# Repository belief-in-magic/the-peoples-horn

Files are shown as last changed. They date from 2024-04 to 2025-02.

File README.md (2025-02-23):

# HERE LIES

This project is no longer actively developed. 

I've decided to open-source all the components (pcb, case design, and firmware) for anyone interested. There are a couple of bits that may be useful
for anyone trying to do something similar.

Please see [EPILOGUE.md](/EPILOGUE.md) for more details

# The People's Horn

One word: WHIMSY.

The People's Horn is a portable soundboard that can be operated with a single hand. 
The chorded input interface allows for 15 (2^4-1) sounds to be played. 

## DEMO

https://github.com/user-attachments/assets/fd60f254-f890-4aff-ada0-f0f0ac13cf6f

## Basic usage

- On the main board (the one with the RP2040, uSD slot, and USB-C connector), there should be a power jumper (POWER_EN)
This needs to be shorted for the board to power on.
- Slot in the microSD card with sound files stored inside. The format and naming of said sound files are explained below.
- Insert the speaker leads into the green terminal block. Note the polarity of the leads. ([PCB/v0.2 only] There aren't any signifiers for the polarity of the leads on the PCB. The one 
soldered to the square pad on the PCB is the positive one.)
- Connect the IO board with the main board using the JST connector.
- Compile and upload the firmware. This is described in the firmware directory README.

## Loading files

Sound files are stored in an external uSD card. Current limitations in the hardware require that the sound files to be in a certain format. Notably they need to be in `.wav` format, with a mono 44.1kHz sampling rate.

Here is a nice ffmpeg command to convert an example file `0001.mp3` into a compliant `wav` file:

```
ffmpeg -i 0001.mp3 -f wav  -flags +bitexact -map_metadata -1 -ar 44100 -ac 1 -af "highpass=f=120,highpass=f=100,lowpass=f=19000,lowpass=f=20000" 0001.wav
```

The names of the final sound files also need to follow a specific format: `[0|1][0|1][0|1][0|1].wav` (e.g. `1001.wav`, `0111.wav`). The number in the filename represents the buttons to
press in order to play it. The lowest order bit represents the button closest to the rotary encoder. The highest order bit is the one furthest away.

## Current Bugs:

- [PCB/v0.3]: Current main board seems to not work directly on USB power. If the battery is not connected but the USB port is,
the board should power on. This is not the case with v0.2. This might be caused by the main inductor backdriving (?). This is hopefully fixed with the new diode placement.
  - Update: this is still the case with v0.3 :( 

## TODO + Possible Improvements:

- [PCB]: Power usage testing. Test low power mode for the rp2040. 
  - How long does it take to fully charge? 
  - How long does a charge last idle?
  - Does using the rp2040 lower power mode make sense?
- [PCB]: Separate 3.3V and 5V converters from battery. Currently we use a 3.3V LDO regulator on the boosted 5V source, this isn't the most
efficient. If we have a separate 3.3V SMPS from battery, we could also disable the 5V converter during lower power situations, allowing for
even more energy savings.

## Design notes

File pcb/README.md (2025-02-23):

# PCB

KiCAD (6.0) schematic and PCB files.

There are technically two KiCAD projects here. One for the "main" board and one for the
IO board. 

Supporting multiple PCBs in one KiCAD project is kinda janky right now. So it was decided 
to use different projects. This allows us to iterate separately on these boards. It also seems to be
easier for fab houses to process and manufacture, without dramatically increasing the price. 

We might have to eventually reconsider using two separate projects for scale and cost purposes, but for dev work this seems to work fine.

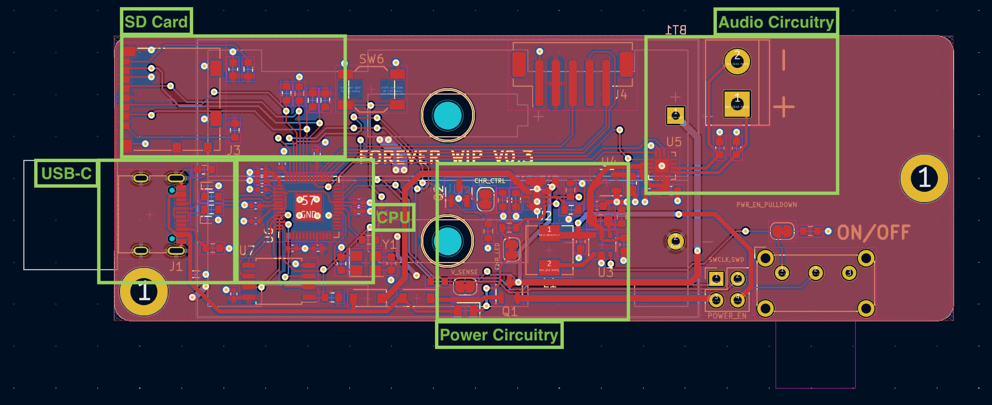
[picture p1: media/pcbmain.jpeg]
main board pcb


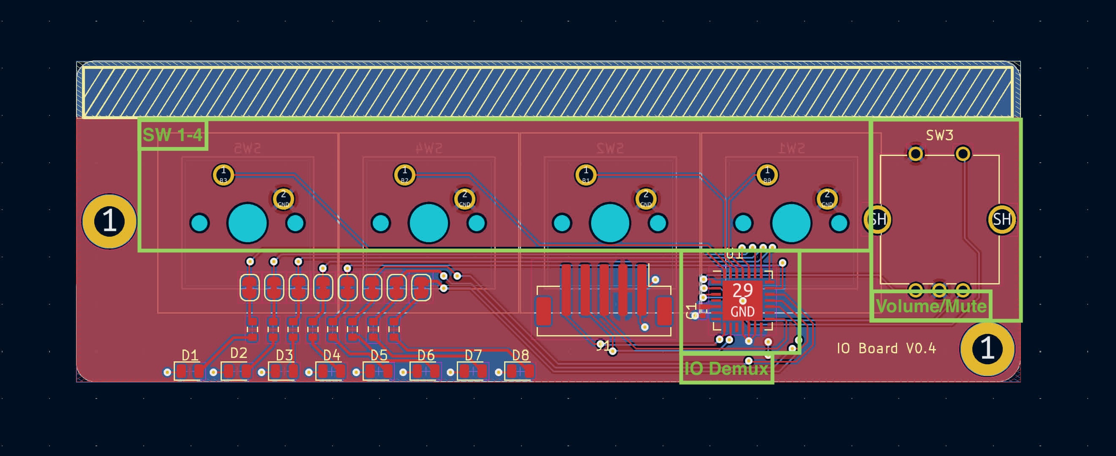
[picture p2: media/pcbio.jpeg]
io board pcb


## Version:

[VERSION 0.3] 
SHA: e7d5517

## Preparing boards for manufacturing

TODO

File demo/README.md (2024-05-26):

# Demo script to test with keyboard

Python script to test basic UX for chorded sounds. Just a demo. Not used in any
way in the main project.

Needs pygame:
```
pip3 install pygame
```

Run:
```
python3 keyboard.py
```

A small blank screen will appear once you run the script. 
Click on the screen and play sounds with the 1,2,3,4 keyboard keys.
Cancel all currently playing sounds with spacebar.

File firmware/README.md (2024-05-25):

# Firmware source code

Arduino sketch for main board. We use the arduino-cli and an open-source rp2040 core.
Arduino was chose here for its ease of use and the breadth of its peripheral libraries.

## Install:
Run this within the containing directory:
```
# Install arduino-cli in local directory
curl -fsSL https://raw.githubusercontent.com/arduino/arduino-cli/master/install.sh | BINDIR=$PWD sh

# Install arduino rp2040 core 
./arduino-cli config add board_manager.additional_urls  https://github.com/earlephilhower/arduino-pico/releases/download/global/package_rp2040_index.json
./arduino-cli core update-index
./arduino-cli core install rp2040:rp2040
```

### Compiling:

```
./arduino-cli compile --fqbn rp2040:rp2040:rpipico main
```

### Uploading:

```
./arduino-cli upload -p /dev/ttyACM0 --fqbn rp2040:rp2040:rpipico main
```

## Serial debugging:

You can start a serial connection with minicom:

```
minicom -D /dev/ttyACM0 -b 115200
```

## Language Server

TODO: I can't get this fucking thing to work

```
./arduino-language-server \
 -clangd /usr/bin/clangd \
 -cli ../arduino-cli \
 -cli-config $HOME/.arduino15/arduino-cli.yaml \
 -fqbn rp2040:rp2040:rpipico main
```

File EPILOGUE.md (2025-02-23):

# Epilogue

*This project is no longer actively developed!!!*

I've decided to open-source all the components (PCB, case design, and firmware) for anyone interested. There are a couple of bits that may be useful
for anyone trying to do something similar.

Firmware:
- How to read wav files from an sd interface and play multiple at once
- Control logic for a chorded input type-thing
- Using software fifo-queues for orchestrating the two RP2040 cores 

PCB:
- Reading from an SD card (using SPI) using an RP2040 chip 
- NiMh battery charging circuitry (honestly this is probably kinda buggy)
- Probably more...

## Writeup

I started this project back in November 2023 (roughly 1.5 years ago) and worked on it (on and off) for almost a year.
Development stopped when my personal priorities shifted and I started looking for a new job. The new job I landed
requires more of my energy and I don't see myself working on this project in the future. 

It wasn't for nothing though! I learnt a lot. I even took some prototypes out with me during hangouts with friends. This thing really is a tomfoolery device. 

I would say this project is probably around 90% complete; the core functionality is there, and what's left is mainly ironing out some hardware bugs
and polishing. (I say 90% done, but the last 10% is probably another 90% of work!) It's unfortunate that I'm not neatly tying everything up here, but I
feel like I've personally squeezed out everything I want from this project. 

This project was definitely a learning experience:
- Designing a custom PCB and shipping its various iterations for manufacturing was really fun. I've acquired a new appreciation for how fast
iteration cycles are for software. It was also really expensive! Canadian tariffs on PCBs really add up!
- Writing software for hardware that you've personally designed is also fun. I've never had to think about whether a feature should be represented in hardware or
software. I've also never really debugged issues where I was unsure if the problem came from the hardware or software! These were all very novel 
experiences for me.
- Designing the case presented me with some unfamiliar design challenges. The intent was to be able to use the horn with just one hand. I had to consider 
seemingly obvious design-y things: Can this be comfortably held? Is the mute button easily accesible? Is the case handle the occasional drop? 
I had to do this all while factoring in the physical constraints brought on by the PCBs. 

I had also originally intended to sell a couple of these. (I think the personal target I set for myself was 100?) Looking back, this was a pretty misguided
endeavor and I'm glad I didn't really continue there. The unit economics just didn't add up. I'd have to sell an individual unit for like $100, which is
way too much for a toy like this. There's also incorporating into a company, setting up manufacturing contracts, QA and insurance, marketing, setting up a website,
handling storage, handling returns, etc etc. Maybe for a different product in the future, but not this one.

## Technical stuff

All the components of this project (the case, PCB, software) went through at least one redesign, each. (A pattern I've noticed in nearly all my personal projects.)

### Firmware: 

The V1 firmware used shared memory and locks to communicate between the two RP2040 cores. One would look for user input chords, and the other would read from the sd card interface
and drive the speakers. Debugging this setup was a *complete* nightmare. This was at least partly due to my inexperience with lower level multiprocessing. The dance between
reading sd contents to memory buffers, getting "interrupted" by the IO core, and driving the audio chip became really clumsy, really fast. That was also exhasperbated by fact that multiple
sounds could be played at the same time (4 sounds to be exact, so 4 different sound buffers). The max number of sounds was mainly constrained
by how fast the RP2040 could read from the SD card (in SPI mode, not SDIO, which probably has higher throughput but is also harder to implement). If the max number of sounds was playing and
the user triggered another one, the least recently used sound would be evicted. The LRU eviction strategy seemed like the most intuitive for users.

At some point I hit a wall with V1 and decided to try something different.
V2 of the firmware replaced the shared memory and locks with some thread-safe FIFO queues. Two to be exact, one for core 1 to send messages to core 2, and another for the opposite direction. 
The cores would send messages to each other like "TRIGGER SOUND X", "STOP BUFFER Y", "READ SD SECTOR 2 FOR BUFFER Z" as their main coordination mechanism. This incurs a theoretical performance 
hit, but makes it easy to linearize what's going on in an individual buffer. This makes debugging a lot more pleasant.

Multicore processing is just hard. Even in the two core scenario, I struggled to wrap my head around all the possible states the system could be in. 
Always look into ways (e.g linearizing your state) to make reasoning simpler.

### PCB:

I felt most out of my element here. The PCBs went through 2 main designs, the latter mainly to shrink the footprints and reorient how they're placed within the case:

PCB images, left is V1, right is V2:

Fronts:
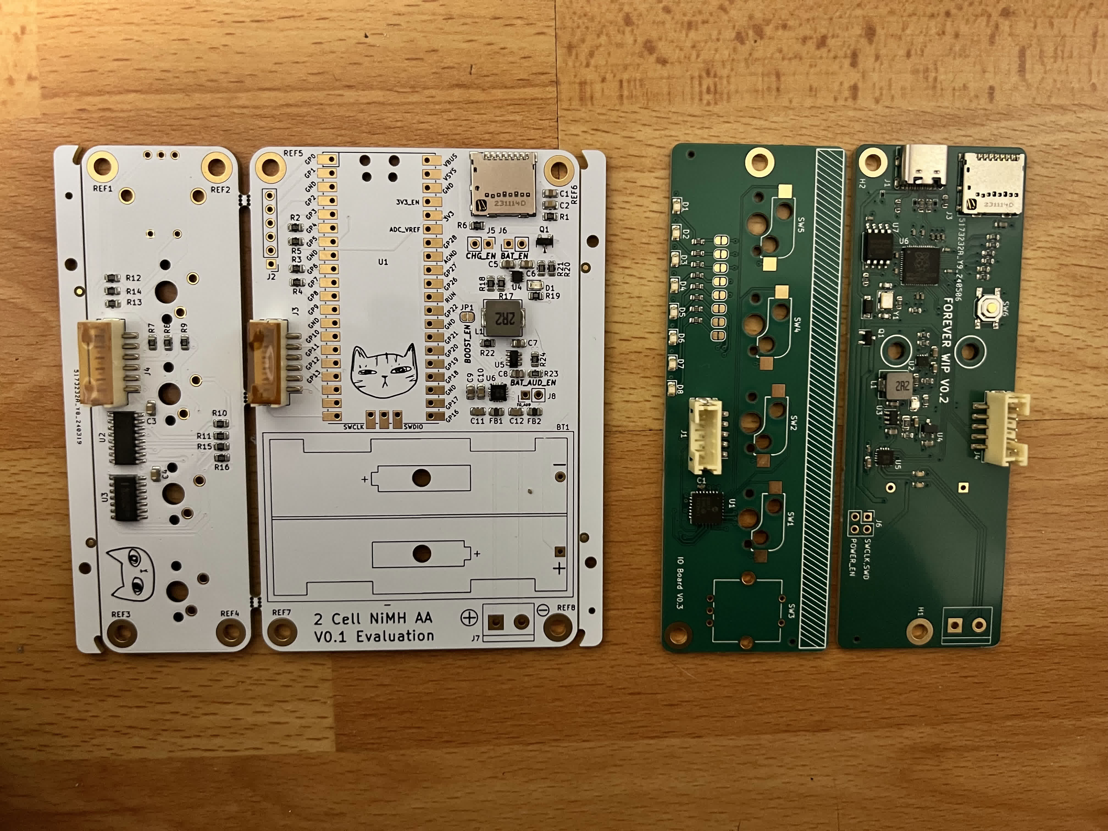
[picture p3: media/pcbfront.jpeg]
fronts


Backs:
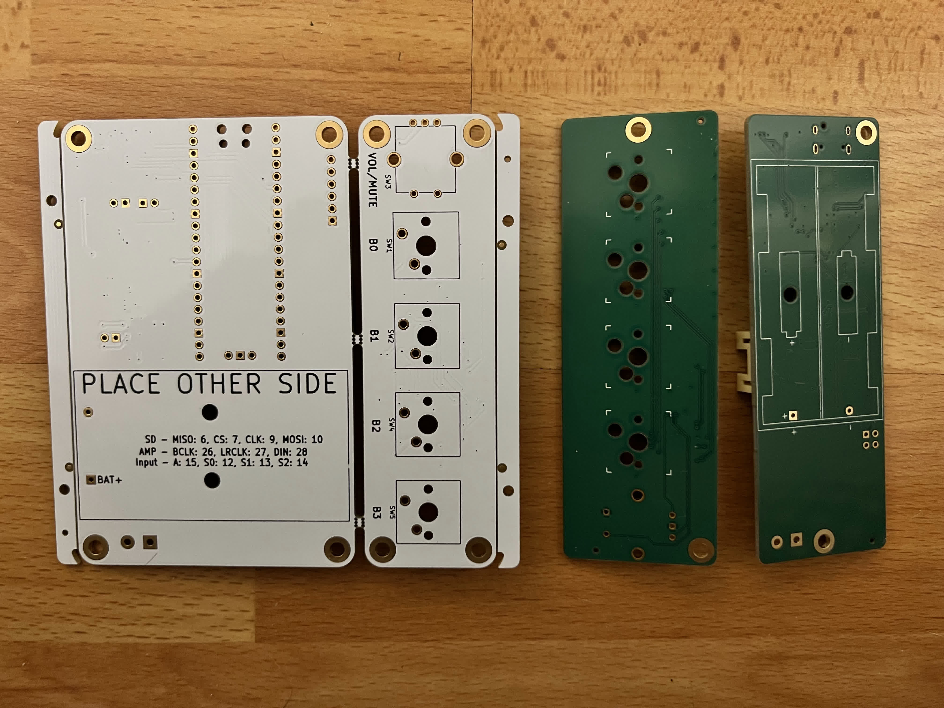
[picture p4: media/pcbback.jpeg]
backs


Most of the circuitry was hacked together by looking at online tutorials. Oftentimes, if I was choosing between two components for something (like an amp IC), I would end
up choosing the one with the Adadruit or Sparkfun breakout board and tutorial. Whether the PCB assembly manufacturer had it in stock would also sometimes be a deciding factor. 

I also had to dive into the occasional datasheet for the various ICs I chose. I still don't think my
power+charging circuitry is without bugs. I chose to use NiMH batteries for this project because it seemed to me to be the most accessible rechargeble batteries that wouldn't set the house on fire
if something was wrong. Turns out NiMH charging ICs are a bit more rare (lithium ion charging ICs are way more common), and the only resource online I had to go off of
for the chip I chose was the online datasheet. Maybe if I was a more skilled hardware designer I would have gotten it right on the first iteration, but the charging logic turned out to be surprisingly
difficult. (For example, making sure the device still runs if the battery is removed, but the device is plugged in.)

Getting the PCB footprint right was also really difficult. I tried to use as many SMD components as possible, and have them all placed on one side (for both pcbs). This was so I could use the PCBA service provided from
JLC. I HATE soldering.

Sending my designed parts to a PCB manufacturer was a fun experience. I used JLCPCB for my design (I also used their PCBA service for SMD parts) and I have no complaints. It's honestly suprising 
how fast they can manufacture a design and ship it out. I think it would normally take 2 weeks, from sending the design, to the parts reaching me in Toronto. Very nice service. 

### Builds

##### v1 (very boxy):
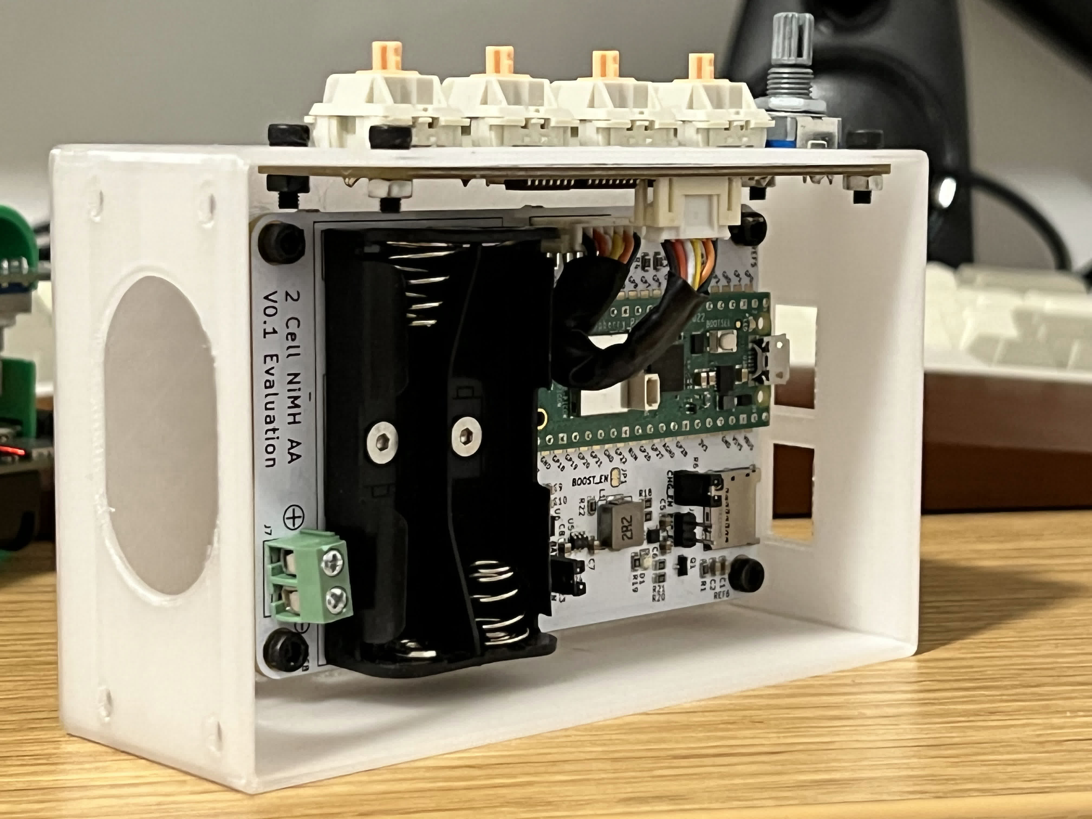
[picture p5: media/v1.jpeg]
V1 test build (missing speaker)


##### v2 (rounder, more compact):
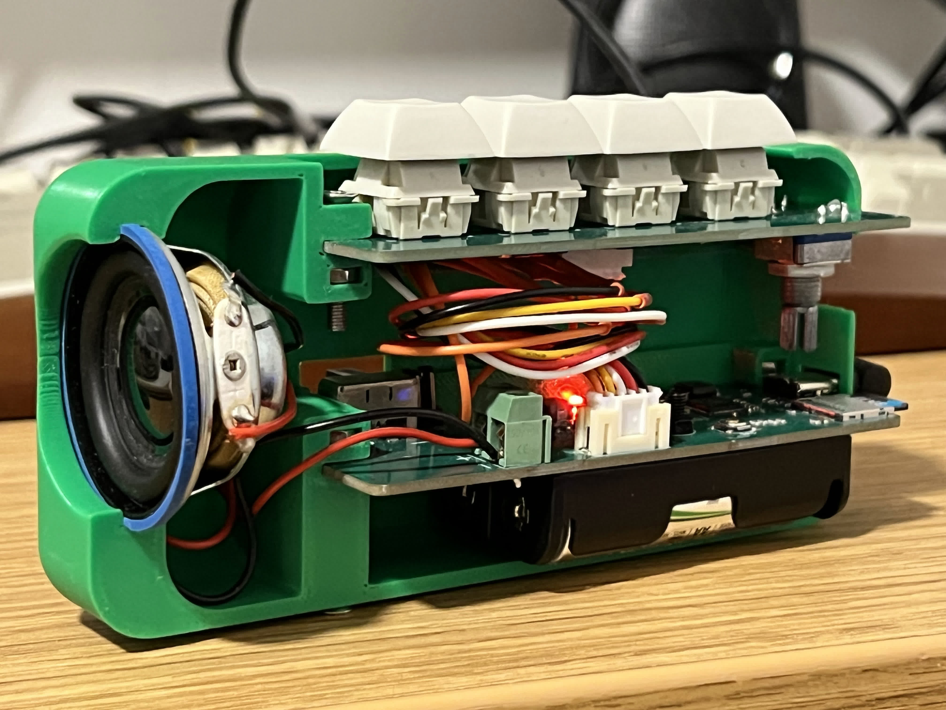
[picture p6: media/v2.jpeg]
V2 test build


##### side by side (note how v2 is much smaller and streamlined):
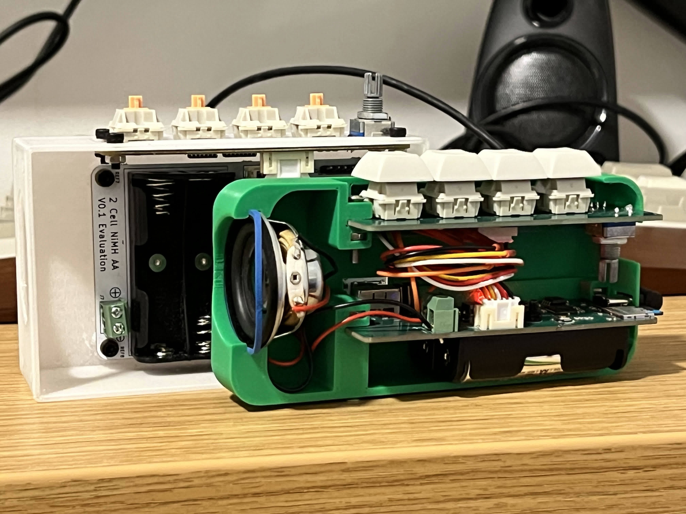
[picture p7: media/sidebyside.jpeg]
side by side


## FIN

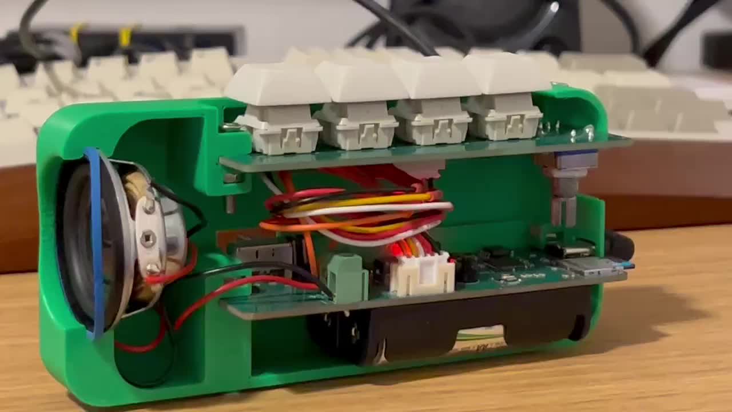
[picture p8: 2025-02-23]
media/output.jpeg

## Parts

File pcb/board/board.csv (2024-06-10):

Comment | Designator | Footprint | LCSC
10uF | C1,C4,C5,C7,C8,C9,C10 | Capacitor_SMD:C_0603_1608Metric | C19702
100nF | C11,C16,C17,C19,C21,C22,C23,C24,C25,C26,C27 | Capacitor_SMD:C_0402_1005Metric | C307331
220pF | C12,C13 | Capacitor_SMD:C_0603_1608Metric | C1603
27pF | C14,C15 | Capacitor_SMD:C_0603_1608Metric | C107045
1uF | C18,C20 | Capacitor_SMD:C_0402_1005Metric | C52923
22uF | C6 | Capacitor_SMD:C_0603_1608Metric | C59461
DF2S6.8FS | D1,D2,D3 | Diode_SMD:D_SOD-923 | C1972978
B5819W SL | D4,D6 | Diode_SMD:D_SOD-123 | C8598
CHARGE_LED | D5 | LED_SMD:LED_0805_2012Metric | C84256
USB_C_Receptacle_USB2.0 | J1 | Connector_USB:USB_C_Receptacle_G-Switch_GT-USB-7010ASV | C2988369
Micro_SD_Card_Det | J3 | Connector_Card:microSD_HC_Molex_104031-0811 | C585350
Conn_01x05_Male | J4 | Connector_JST:JST_PH_B5B-PH-SM4-TB_1x05-1MP_P2.00mm_Vertical | C265085
2.2uH | L1 | Inductor_SMD:L_Sunlord_MWSA05xxS | C408408
DMG2305UX | Q1 | Package_TO_SOT_SMD:SOT-23 | C2940629
AO3400A | Q2 | Package_TO_SOT_SMD:SOT-23 | C20917
5.1K | R1,R2 | Resistor_SMD:R_0603_1608Metric | C23186
1K | R11,R18,R19 | Resistor_SMD:R_0603_1608Metric | C21190
2K7 | R13,R15 | Resistor_SMD:R_0603_1608Metric | C13167
24.3K | R14 | Resistor_SMD:R_0805_2012Metric | C204336
27K | R16,R17,R22,R23 | Resistor_SMD:R_0603_1608Metric | C22967
10K | R3,R4,R5,R6,R7,R8,R12,R20,R21 | Resistor_SMD:R_0603_1608Metric | C25804
27R | R9,R10 | Resistor_SMD:R_0603_1608Metric | C25190
BOOTSEL | SW6 | Button_Switch_SMD:SW_SPST_SKQG_WithoutStem | C318884
BQ25172 | U2 | Package_SON:WSON-8-1EP_2x2mm_P0.5mm_EP0.9x1.6mm | C5189434
TLV61070A | U3 | Package_SO:TSOP-6_1.65x3.05mm_P0.95mm | C6881375
XC6206P332MR | U4 | Package_TO_SOT_SMD:SOT-23-3 | C5446
MAX98357 | U5 | Package_DFN_QFN:TQFN-16-1EP_3x3mm_P0.5mm_EP1.6x1.6mm | C910544
RP2040 | U6 | Package_DFN_QFN:QFN-56-1EP_7x7mm_P0.4mm_EP3.2x3.2mm | C2040
W25Q128JVS | U7 | Package_SO:SOIC-8_5.23x5.23mm_P1.27mm | C97521
X322512MSB4SI | Y1 | Crystal:Crystal_SMD_3225-4Pin_3.2x2.5mm | C9002

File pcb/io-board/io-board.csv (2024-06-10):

Comment | Designator | Footprint | LCSC
100nF | C1 | Capacitor_SMD:C_0402_1005Metric | C307331
LED | D1,D2,D3,D4,D5,D6,D7,D8 | LED_SMD:LED_0805_2012Metric | C2297
MountingHole | H1,H2 | MountingHole:MountingHole_3.2mm_M3_DIN965_Pad
Conn_01x05_Male | J1 | Connector_JST:JST_PH_B5B-PH-SM4-TB_1x05-1MP_P2.00mm_Vertical | C265085
Jumper_2_Bridged | JP1,JP2,JP3,JP4,JP5,JP6,JP7,JP8 | Jumper:SolderJumper-2_P1.3mm_Bridged_RoundedPad1.0x1.5mm
2K7 | R1,R2,R3,R4,R5,R6,R7,R8 | Resistor_SMD:R_0603_1608Metric | C13167
SW_Keyboard | SW1,SW2,SW4,SW5 | Library:Kailh_socket_MX | C5156480
RotEncoder_S | SW3 | Rotary_Encoder:RotaryEncoder_Bourns_Vertical_PEC12R-3xxxF-Sxxxx
MCP23017_ML | U1 | Package_DFN_QFN:QFN-28-1EP_6x6mm_P0.65mm_EP4.25x4.25mm | C629439

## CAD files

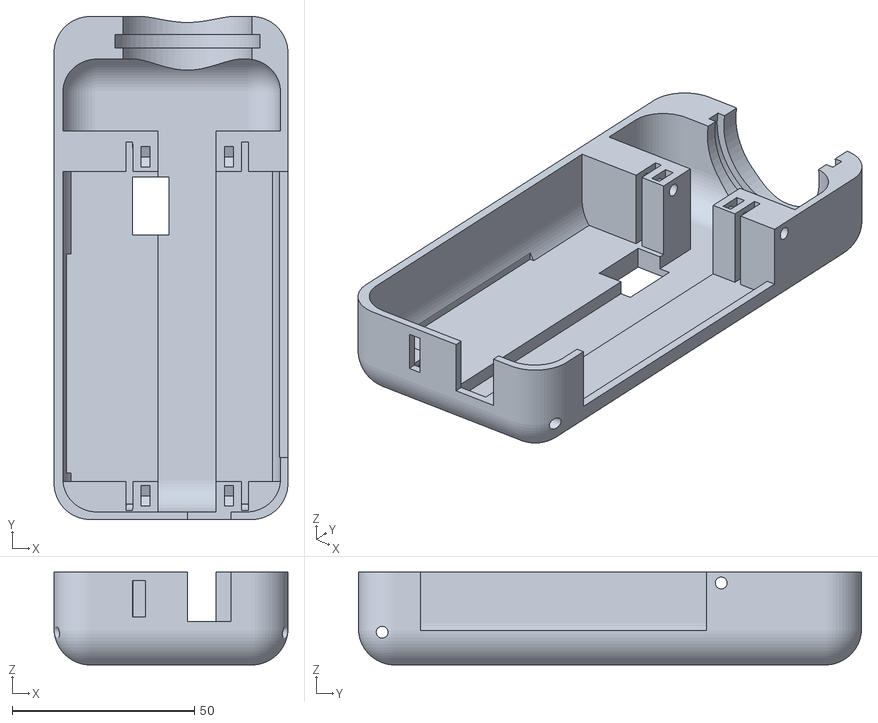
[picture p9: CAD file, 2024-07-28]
case/t2.stl
64.2 x 138.0 x 25.5

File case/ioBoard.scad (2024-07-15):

include <dimensions.scad>
include <math.scad>
include <screws.scad>


ioBoardSwitchSpace = 5;

module ioBoard(negative=false) {

    difference() {

        union() {
            pcb();

            if (negative) cutouts();
        }

        for (hole = ioBoardHoles) {
            translate(v=[hole[0],hole[1],-inf/2])
            cylinder(r=m3Radius, h=inf);
        }

    }

    module pcb() {
        translate(v=[pcbR, pcbR, 0])
            color(c=pcbColor) // pcb green
            minkowski() {
            cube(size=[ioBoardX-pcbR*2, ioBoardY-pcbR*2, pcbThickness]);
            cylinder(h=eps, r=pcbR);
        }
    }

    module cutouts() {

        knobCutoutX = 21.00;
        knobCutoutZ = 12.00;

        knobCutoutDx = (ioBoardX-knobCutoutX)/2.00;
        knobCutoutDz = -15.00;

        keySwitchCutoutX = 25.00;
        keySwitchCutoutY = 78.50;

        keySwitchCutoutDx = 5;
        keySwitchCutoutDy = 14;


        color(c=[1,0,0]) {
            // knob
            translate(v=[knobCutoutDx, -inf, knobCutoutDz])
            cube(size=[knobCutoutX, inf, knobCutoutZ]);

            // key switches
            translate(v=[keySwitchCutoutDx, keySwitchCutoutDy, pcbThickness])
            cube(size=[keySwitchCutoutX, keySwitchCutoutY, 20]);
    
            translate(v=[keySwitchCutoutDx, keySwitchCutoutDy, pcbThickness + ioBoardSwitchSpace])
            cube(size=[keySwitchCutoutX, keySwitchCutoutY+8, 20]);
            
            
        }
    }
}

*ioBoard(negative=true);

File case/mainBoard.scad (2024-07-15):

include <dimensions.scad>
include <math.scad>
include <screws.scad>


// TODO: extract pcb shape as separate module, and use it as a negative in pcbFrame
module mainBoard(negative=false) {
    
    difference() {
        
        union() {
            pcb();
            batteryHolder();

            if (negative) cutouts();
        }

        for (hole = mainBoardHoles) {
            translate(v=[hole[0],hole[1],-inf/2])
            cylinder(r=m3Radius, h=inf);
        }
    }


    module pcb() {
        translate(v=[pcbR, pcbR, 0])
            color(c=pcbColor) // pcb green
            minkowski() {
            cube(size=[mainBoardX-pcbR*2, mainBoardY-pcbR*2, pcbThickness]);
            cylinder(h=eps, r=pcbR);
        }
    }

    module batteryHolder() {
        batteryY = 60.00;
        batteryX = mainBoardX;
        batteryZ = 16.5;

        batteryDy = 9.80;

        mirror(v=[0,0,1])
        translate(v=[0,batteryDy,0])
        cube(size=[batteryX, batteryY, batteryZ]);
    }

    module cutouts() {

        usbCutoutX = 10.00;
        usbCutoutZ = 3.50;

        usbCutoutDx = mainBoardX - 12.70; // from edge of PCB to midpoint of USB cutout
        usbCutoutDy = 0.00;

        sdCutoutX = 12.50;
        sdCutoutZ = 3.00;

        sdCutoutDx = mainBoardX - 26.70;  // from edge of PCB to midpoint of SD card cutout
        sdCutoutDy = 0.00;

        powerSwitchCutoutY = 16;
        powerSwitchCutoutZ = 10;
        powerSwitchCutoutDx = 25;
        powerSwitchCutoutDy = 75;

            

        color(c=[1,0,0]) {

            translate(v=[-usbCutoutX/2 + usbCutoutDx, -inf + usbCutoutDy, pcbThickness])
                cube(size=[usbCutoutX, inf, usbCutoutZ]);

            translate(v=[-sdCutoutX/2 + sdCutoutDx, -inf + sdCutoutDy, pcbThickness])
                cube(size=[sdCutoutX, inf, sdCutoutZ]);

            translate(v=[powerSwitchCutoutDx, powerSwitchCutoutDy, pcbThickness])
                cube(size=[inf, powerSwitchCutoutY, powerSwitchCutoutZ]);
            
        }
    }

}

mainBoard(negative=true);

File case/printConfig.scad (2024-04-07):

/**********************************************************************************************************************
  Slack config to standardize different usages of slack/tolerance values.

  The purpose of this config is to introduce some consistency with how slack values defined in code. E.g. Why is the
  slack value defined as 0.3 in this file, but 0.4 in another? This will also allow model-level adjustments for tighter
  fitting parts, for when it might not convenient to adjust the actual 3d printer (using a 3d printer at a makerspace,
  for example).

  Some important details:
    - The general philosophy for slack applications in this project is to subtract space from sockets, while not
      modifying the plugs.
    - Values are signed. Positive values can be interpreted as how much to remove from the socket along some dimension.
    - These values depend on print orientation and it's assumed parts are printed in their recommended orientations.
*/
xySlack = 0.25;

radiusXYSlack = xySlack/2;

zSlack = 0.0;

overhangSlack = 0.5;

supportedOverhangSlack = 0.5;

// special slack cases, change if neccessary
xBarYBarDovetailSlack = xySlack;

/**********************************************************************************************************************
  Printer/slicer config, mainly used for calculating some special overhangs.
*/
defaultLayerHeight = 0.3;

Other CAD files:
case/bodyShape.scad
case/bottomCase.scad
case/dimensions.scad
case/math.scad
case/pcbFrame.scad
case/screws.scad
case/speaker.scad
case/topLid.scad

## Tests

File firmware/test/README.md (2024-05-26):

# Arduino sketches to test basic functionality

## Running

These are compiled+uploaded the same way as the main sketch. For example:

```
../arduino-cli compile --fqbn rp2040:rp2040:rpipico hello-world
../arduino-cli upload -p /dev/ttyACM0 --fqbn rp2040:rp2040:rpipico hello-world
```

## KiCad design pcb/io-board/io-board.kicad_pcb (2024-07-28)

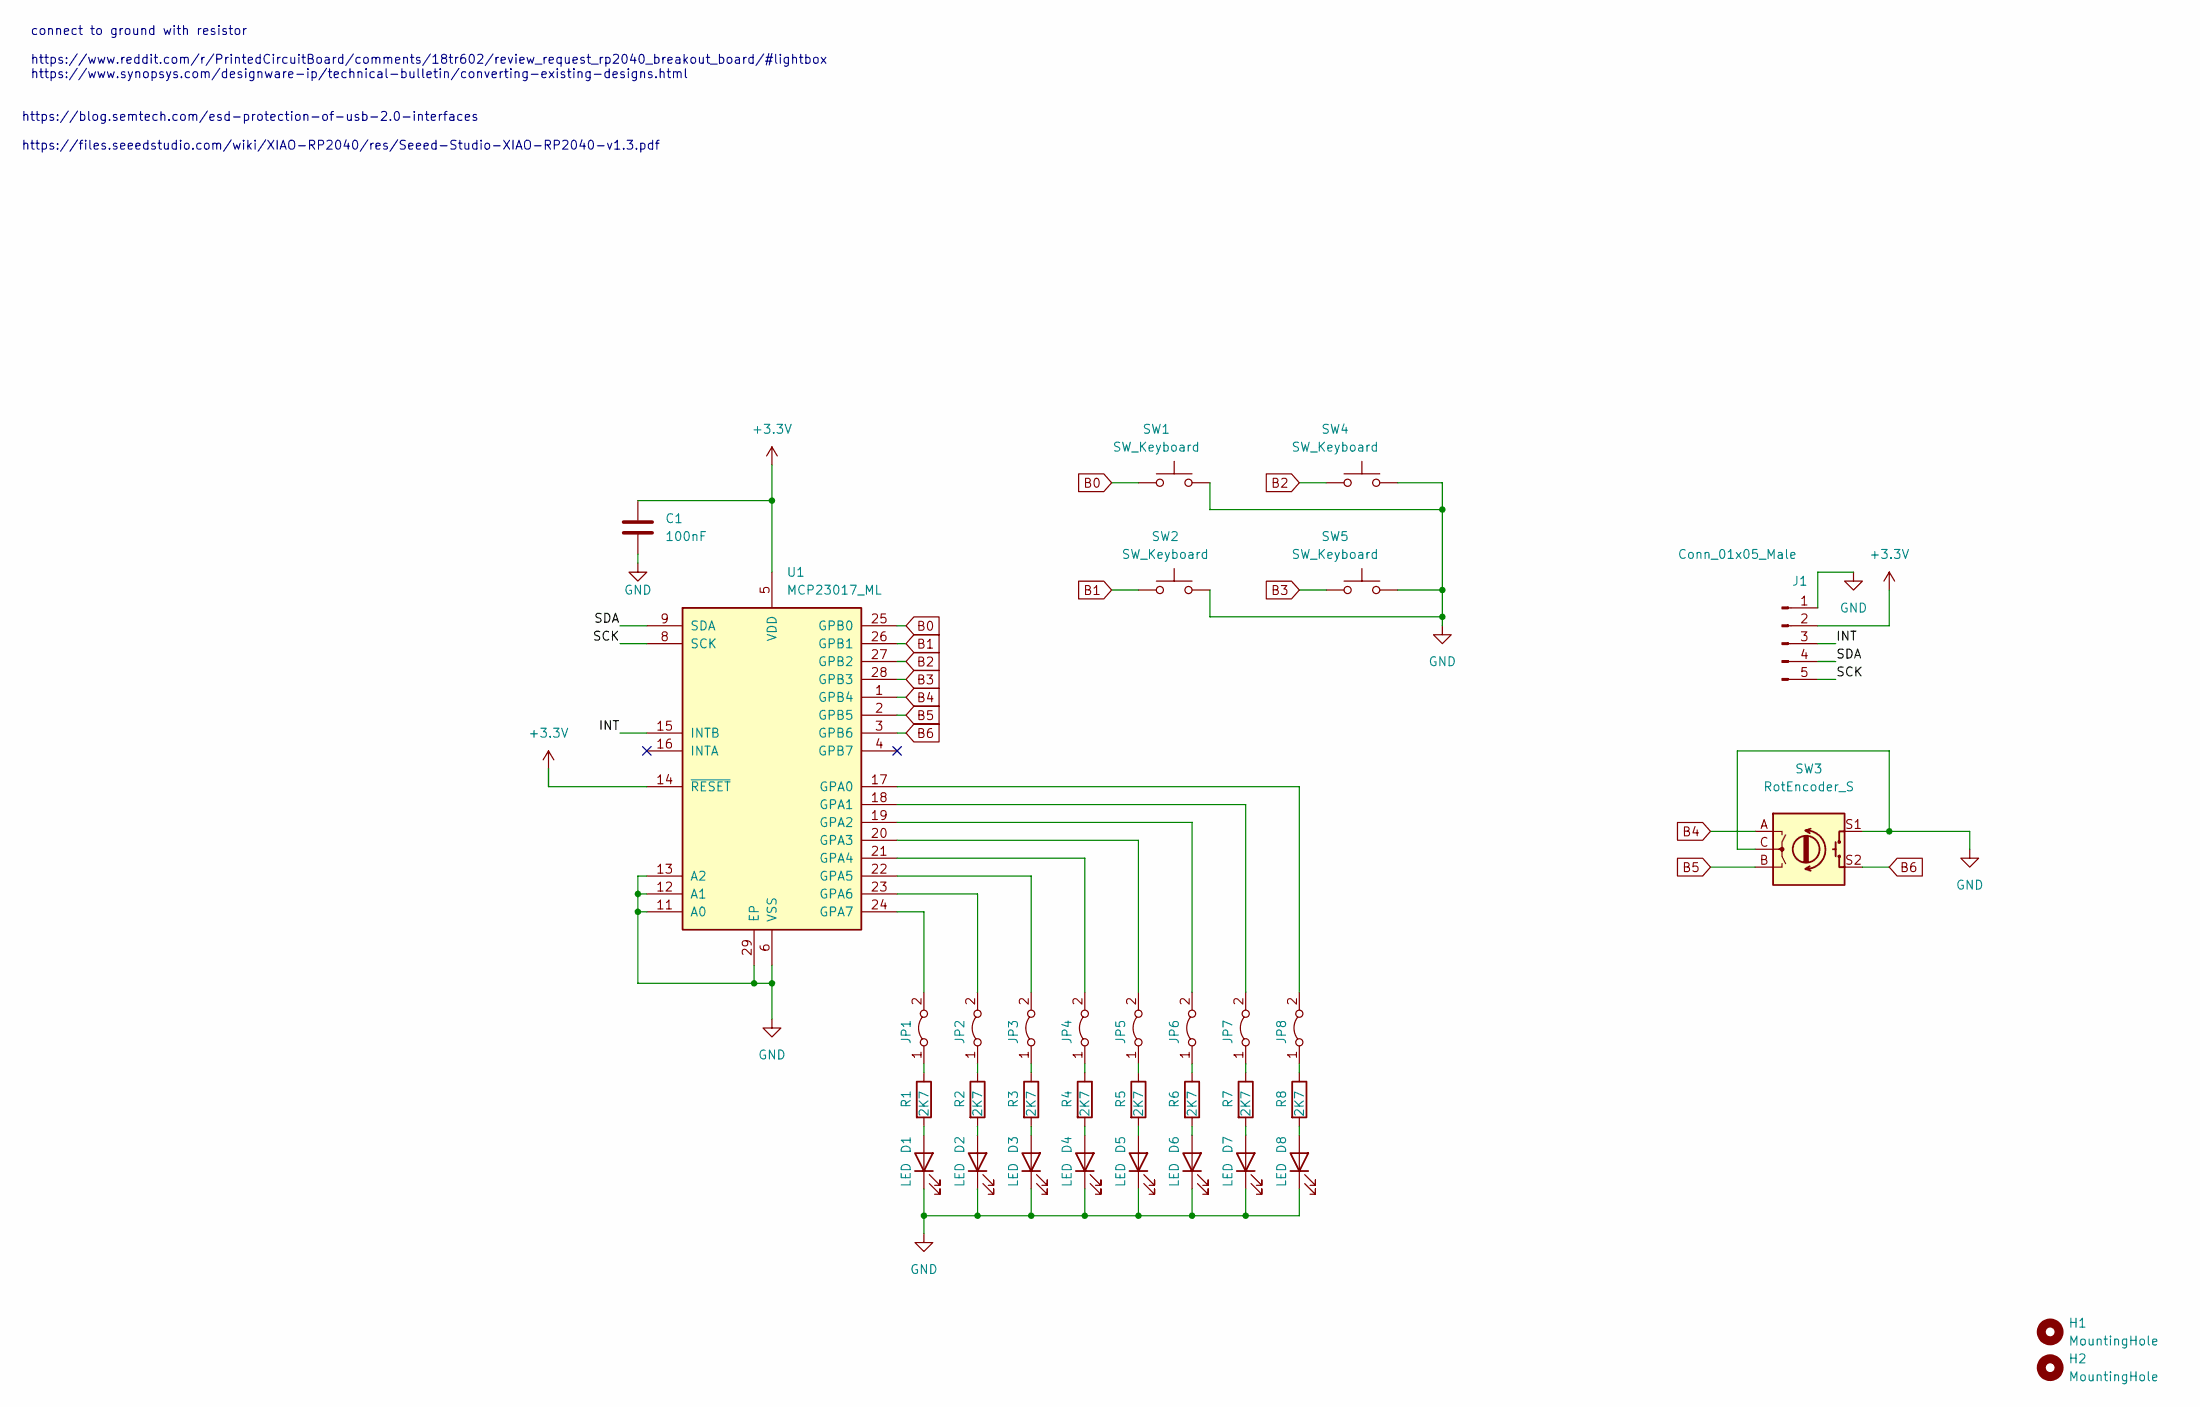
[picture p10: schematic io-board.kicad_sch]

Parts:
C1: 100nF; C_0402_1005Metric
D1, D2, D3, D4, D5, D6, D7, D8: LED; LED_0805_2012Metric
H1, H2: MountingHole; MountingHole_3.2mm_M3_DIN965_Pad
J1: Conn_01x05_Male; JST_PH_B5B-PH-SM4-TB_1x05-1MP_P2.00mm_Vertical
JP1, JP2, JP3, JP4, JP5, JP6, JP7, JP8: Jumper_2_Bridged; SolderJumper-2_P1.3mm_Bridged_RoundedPad1.0x1.5mm
R1, R2, R3, R4, R5, R6, R7, R8: 2K7; R_0603_1608Metric
SW1, SW2, SW4, SW5: SW_Keyboard; SW_Cherry_MX_1.00u_PCB
SW3: RotEncoder_S; RotaryEncoder_Bourns_Vertical_PEC12R-3xxxF-Sxxxx
U1: MCP23017_ML; QFN-28-1EP_6x6mm_P0.65mm_EP4.25x4.25mm

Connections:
+3.3V: C1.1, J1.2, U1.5 (VDD), U1.14 (~RESET)
/INT: J1.3, U1.15 (INTB)
/SCK: J1.5, U1.8 (SCK)
/SDA: J1.4, U1.9 (SDA)
B0: SW1.1, U1.25 (GPB0)
B1: SW2.1, U1.26 (GPB1)
B2: SW4.1, U1.27 (GPB2)
B3: SW5.1, U1.28 (GPB3)
B4: SW3.A, U1.1 (GPB4)
B5: SW3.B, U1.2 (GPB5)
B6: SW3.S2, U1.3 (GPB6)
GND: C1.2, D1.1 (K), D2.1 (K), D3.1 (K), D4.1 (K), D5.1 (K), D6.1 (K), D7.1 (K), D8.1 (K), J1.1, SW1.2, SW2.2, SW3.C, SW3.S1, SW4.2, SW5.2, U1.6 (VSS), U1.11 (A0), U1.12 (A1), U1.13 (A2), U1.29 (EP)
unnamed: D1.2 (A), R1.2
unnamed: D2.2 (A), R2.2
unnamed: D3.2 (A), R3.2
unnamed: D4.2 (A), R4.2
unnamed: D5.2 (A), R5.2
unnamed: D6.2 (A), R6.2
unnamed: D7.2 (A), R7.2
unnamed: D8.2 (A), R8.2
unnamed: JP1.1 (A), R1.1
unnamed: JP1.2 (B), U1.24 (GPA7)
unnamed: JP2.1 (A), R2.1
unnamed: JP2.2 (B), U1.23 (GPA6)
unnamed: JP3.1 (A), R3.1
unnamed: JP3.2 (B), U1.22 (GPA5)
unnamed: JP4.1 (A), R4.1
unnamed: JP4.2 (B), U1.21 (GPA4)
unnamed: JP5.1 (A), R5.1
unnamed: JP5.2 (B), U1.20 (GPA3)
unnamed: JP6.1 (A), R6.1
unnamed: JP6.2 (B), U1.19 (GPA2)
unnamed: JP7.1 (A), R7.1
unnamed: JP7.2 (B), U1.18 (GPA1)
unnamed: JP8.1 (A), R8.1
unnamed: JP8.2 (B), U1.17 (GPA0)

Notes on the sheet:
https://blog.semtech.com/esd-protection-of-usb-2.0-interfaces https://files.seeedstudio.com/wiki/XIAO-RP2040/res/Seeed-Studio-XIAO-RP2040-v1.3.pdf
connect to ground with resistor https://www.reddit.com/r/PrintedCircuitBoard/comments/18tr602/review_request_rp2040_breakout_board/#lightbox https://www.synopsys.com/designware-ip/technical-bulletin/converting-existing-designs.html

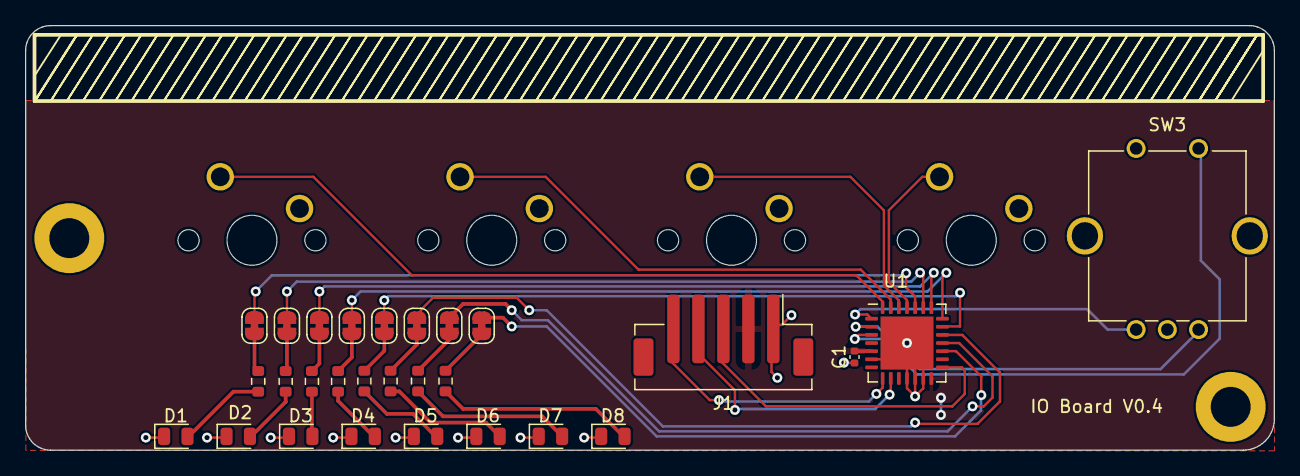
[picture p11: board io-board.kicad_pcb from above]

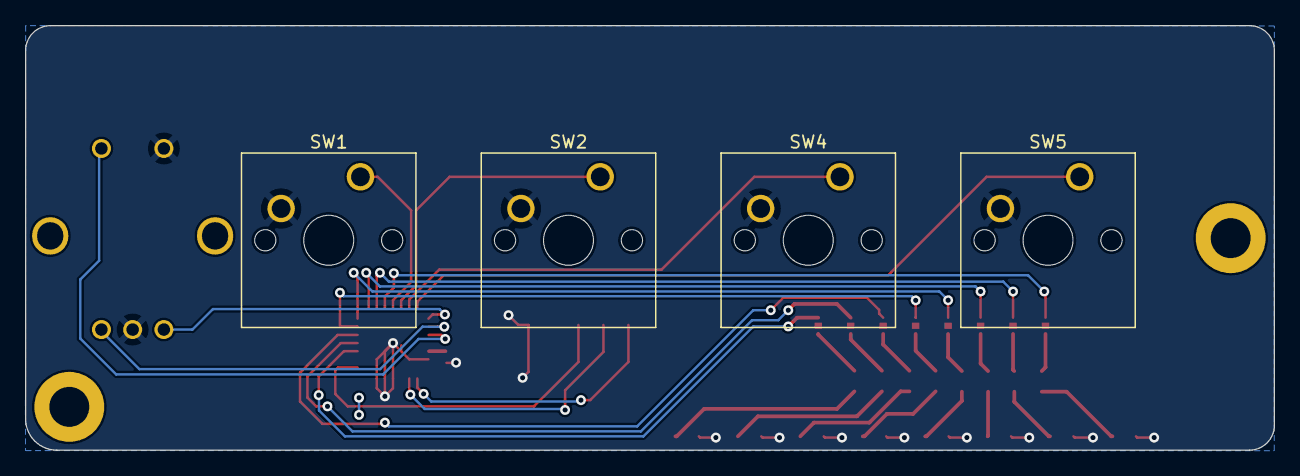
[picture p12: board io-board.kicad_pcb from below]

Board: 2 copper layers, 100.0 x 34.0 mm, 34 parts (4 on the bottom side), 36 nets.

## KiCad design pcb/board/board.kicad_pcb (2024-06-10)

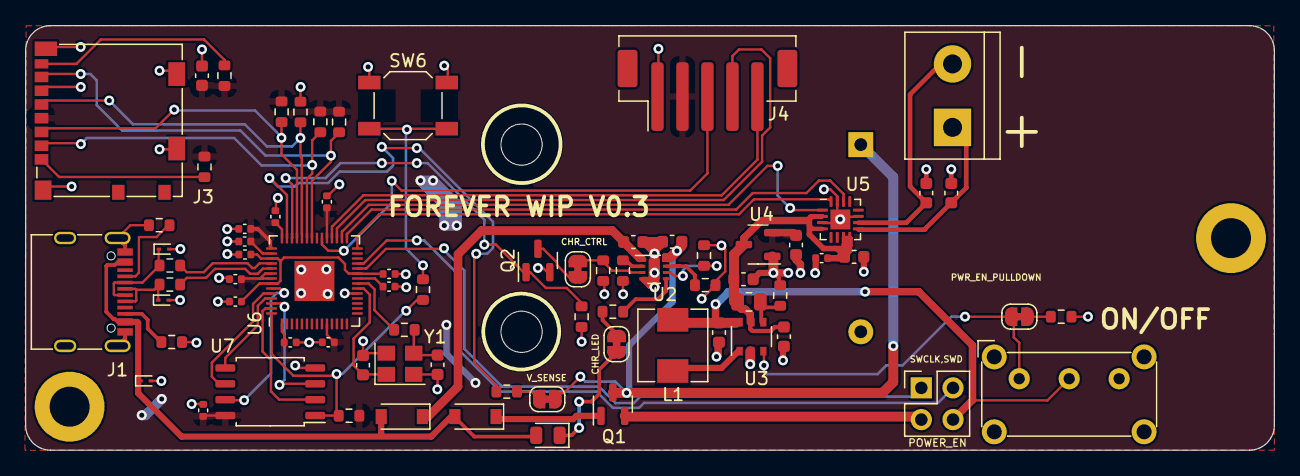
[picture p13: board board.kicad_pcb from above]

Board: 2 copper layers, 100.0 x 34.0 mm, 78 parts (1 on the bottom side), 57 nets.

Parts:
BT1: 3 cell NiMH; BatteryHolder_Keystone_2462_2xAA
C1, C4, C5, C7, C8, C9, C10: 10uF; C_0603_1608Metric
C6: 22uF; C_0603_1608Metric
C11, C16, C17, C19, C21, C22, C23, C24, C25, C26, C27: 100nF; C_0402_1005Metric
C12, C13: 220pF; C_0603_1608Metric
C14, C15: 27pF; C_0603_1608Metric
C18, C20: 1uF; C_0402_1005Metric
D1, D2, D3: DF2S6.8FS; D_SOD-923
D4, D6: B5819W SL; D_SOD-123
D5: CHARGE_LED; LED_0805_2012Metric
H1, H2: MountingHole; MountingHole_3.2mm_M3_DIN965_Pad
J1: USB_C_Receptacle_USB2.0; USB_C_Receptacle_G-Switch_GT-USB-7010ASV
J3: Micro_SD_Card_Det; microSD_HC_Molex_104031-0811
J4: Conn_01x05_Male; JST_PH_B5B-PH-SM4-TB_1x05-1MP_P2.00mm_Vertical
J6: Conn_02x02_Top_Bottom; PinHeader_2x02_P2.54mm_Vertical
J7: Screw_Terminal_Speaker; TerminalBlock_bornier-2_P5.08mm
JP1: CHG_LED_EN; SolderJumper-2_P1.3mm_Bridged_RoundedPad1.0x1.5mm
JP2: CHARGE_CTRL; SolderJumper-2_P1.3mm_Bridged_RoundedPad1.0x1.5mm
JP3: V_SENSE_EN; SolderJumper-2_P1.3mm_Bridged_RoundedPad1.0x1.5mm
JP4: Jumper_2_Bridged; SolderJumper-2_P1.3mm_Bridged_RoundedPad1.0x1.5mm
L1: 2.2uH; L_Sunlord_MWSA05xxS
Q1: DMG2305UX; SOT-23
Q2: AO3400A; SOT-23
R1, R2: 5.1K; R_0603_1608Metric
R3, R4, R5, R6, R7, R8, R12, R20, R21: 10K; R_0603_1608Metric
R9, R10: 27R; R_0603_1608Metric
R11, R18, R19: 1K; R_0603_1608Metric
R13, R15: 2K7; R_0603_1608Metric
R14: 24.3K; R_0805_2012Metric
R16, R17, R22, R23: 27K; R_0603_1608Metric
SW1: PWR; SW_E-Switch_EG1224_SPDT_Angled
SW6: BOOTSEL; SW_SPST_SKQG_WithoutStem
U2: BQ25172; WSON-8-1EP_2x2mm_P0.5mm_EP0.9x1.6mm
U3: TLV61070A; TSOP-6_1.65x3.05mm_P0.95mm
U4: XC6206P332MR; SOT-23-3
U5: MAX98357; TQFN-16-1EP_3x3mm_P0.5mm_EP1.6x1.6mm
U6: RP2040; QFN-56-1EP_7x7mm_P0.4mm_EP3.2x3.2mm
U7: W25Q128JVS; SOIC-8_5.23x5.23mm_P1.27mm
Y1: X322512MSB4SI; Crystal_SMD_3225-4Pin_3.2x2.5mm

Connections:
+1V1: C16.1, C17.1, C18.1, U6.23 (DVDD), U6.45 (VREG_VOUT), U6.50 (DVDD)
+3.3V: C1.1, C9.1, C19.1, C20.1, C21.1, C22.1, C23.1, C24.1, C25.1, C26.1, C27.1, J3.4 (VDD), J4.2, R3.1, R4.1, R6.1, R7.1, R8.1, R20.1, U4.2 (VO), U6.1 (IOVDD), U6.10 (IOVDD), U6.22 (IOVDD), U6.33 (IOVDD), U6.42 (IOVDD), U6.43 (ADC_AVDD), U6.44 (VREG_IN), U6.48 (USB_VDD), U6.49 (IOVDD), U7.8 (VCC)
/Power/BAT_OR_USB_POWER_IN: C5.1, J6.4, L1.1, SW1.2 (B), U3.6 (VIN)
/Power/BAT_OR_USB_POWER_OUT: J6.3, Q1.2 (S)
/USB_D+: R9.2, U6.46 (USB_DM)
/USB_D-: R10.2, U6.47 (USB_DP)
/USB_VBUS: D1.1 (K), D4.2 (A), D5.2 (A), D6.2 (A), J1.A4 (VBUS), J1.A9 (VBUS), J1.B4 (VBUS), J1.B9 (VBUS)
/rp2040/QSPI_SCLK: U6.52 (QSPI_SCLK), U7.6 (CLK)
/rp2040/QSPI_SD0: U6.53 (QSPI_SD0), U7.5 (DI(IO0))
/rp2040/QSPI_SD1: U6.55 (QSPI_SD1), U7.2 (DO(IO1))
/rp2040/QSPI_SD2: U6.54 (QSPI_SD2), U7.3 (IO2)
/rp2040/QSPI_SD3: U6.51 (QSPI_SD3), U7.7 (IO3)
/rp2040/QSPI_SS: R19.2, R20.2, U6.56 (QSPI_SS), U7.1 (~CS)
/rp2040/SWCLK: J6.1, U6.24 (SWCLK)
/rp2040/SWD: J6.2, U6.25 (SWD)
/rp2040/~USB_BOOT: R19.1, SW6.2
AMP_BCLK: U5.16 (BCLK), U6.28 (GPIO17)
AMP_DIN: U5.1 (DIN), U6.30 (GPIO19)
AMP_LRCLK: U5.14 (LRCLK), U6.29 (GPIO18)
CHARGE_EN: Q2.1 (G), R21.2, U6.40 (GPIO28_ADC2)
GND: BT1.2 (-), C1.2, C4.2, C5.2, C6.2, C7.2, C8.2, C9.2, C10.2, C11.2, C12.2, C13.1, C14.1, C15.2, C16.2, C17.2, C18.2, C19.2, C20.2, C21.2, C22.2, C23.2, C24.2, C25.2, C26.2, C27.2, D1.2 (A), D2.2 (A), D3.2 (A), J1.A1 (GND), J1.A12 (GND), J1.B1 (GND), J1.B12 (GND), J1.S1 (SHIELD), J3.6 (VSS), J3.11 (SHIELD), J4.1, Q2.2 (S), R1.1, R2.2, R5.2, R11.1, R12.1, R15.2, R16.2, R17.2, R21.1, R23.2, SW6.1, U2.4 (GND), U2.9 (PAD), U3.2 (GND), U4.1 (GND), U5.3 (GND), U5.11 (GND), U5.15 (GND), U5.17 (THERMAL), U6.19 (TESTEN), U6.57 (GND), U7.4 (GND), Y1.2, Y1.4
INT: J4.3, U6.34 (GPIO22)
unnamed: BT1.1 (+), C7.1, JP3.1 (A), Q1.3 (D), U2.8 (OUT)
unnamed: C4.1, D4.1 (K), U2.1 (IN)
unnamed: C12.1, J7.1, U5.9 (OUTP)
unnamed: C13.2, J7.2, U5.10 (OUTN)
unnamed: C14.2, U6.20 (XIN), Y1.1
unnamed: C15.1, R18.1, Y1.3
unnamed: D2.1 (K), J1.A7 (D-), J1.B7 (D-), R9.1
unnamed: D3.1 (K), J1.A6 (D+), J1.B6 (D+), R10.1
unnamed: D5.1 (K), JP1.1 (A)
unnamed: D6.1 (K), Q1.1 (G)
unnamed: J1.A5 (CC1), R2.1
unnamed: J1.B5 (CC2), R1.2
unnamed: J3.1 (DAT2), R8.2
unnamed: J3.8 (DAT1), R3.2
unnamed: JP1.2 (B), R13.1
unnamed: JP2.1 (A), Q2.3 (D)
unnamed: JP2.2 (B), R12.2, U2.3 (TS)
unnamed: JP3.2 (B), R22.2
unnamed: JP4.1 (A), R23.1
unnamed: JP4.2 (B), SW1.1 (A), U3.3 (EN)
unnamed: L1.2, U3.1 (SW)
unnamed: R11.2, U2.2 (ISET)
unnamed: R13.2, U2.5 (STAT)
unnamed: R14.2, R15.1, U3.4 (FB)
unnamed: R16.1, U2.6 (TMR)
unnamed: R17.1, U2.7 (VSET)
unnamed: R18.2, U6.21 (XOUT)
RP2040_SCL: J4.5, U6.32 (GPIO21)
RP2040_SDA: J4.4, U6.31 (GPIO20)
SD_CLK: J3.5 (CLK), R5.1, U6.38 (GPIO26_ADC0)
SD_CS: J3.2 (DAT3/CD), R7.2, U6.37 (GPIO25)
SD_MISO: J3.7 (DAT0), R4.2, U6.36 (GPIO24)
SD_MOSI: J3.3 (CMD), R6.2, U6.39 (GPIO27_ADC1)
VDD: C6.1, C8.1, C10.1, C11.1, R14.1, U3.5 (VOUT), U4.3 (VI), U5.2 (GAIN), U5.4 (~SD_MODE), U5.7 (VDD), U5.8 (VDD)
V_SENSE: R22.1, U6.41 (GPIO29_ADC3)

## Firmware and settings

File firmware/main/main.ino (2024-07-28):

#include <I2S.h>
#include <SPI.h>
#include <SD.h>
#include <Wire.h>
#include <Adafruit_MCP23X17.h>

#include "interface.h"
#include "input.h"
#include "core0.h"
#include "core1.h"


const int sampleRate = 44100;

// Create the I2S port using a PIO state machine
I2S i2s(OUTPUT);

Adafruit_MCP23X17 mcp;

SharedState sharedState;
Core0State core0State(&sharedState, &i2s);
Core1State core1State(&sharedState);

void setup() {

  Serial.begin(115200);


  Serial.println("BEGIN ****************************************************");

  Serial.println("core0 - starting setup");

  rp2040.fifo.push(123);
  rp2040.fifo.pop(); // wait for the second core's setup to complete first

  core0State.setup();

  Serial.println("core0 - waiting on other core done");

  i2s.setBCLK(SPEAKER_I2S_BCLK);
  i2s.setDATA(SPEAKER_I2S_DOUT);
  i2s.setBitsPerSample(I2S_BITS_PER_SAMPLE);

  // start I2S at the sample rate with 16-bits per sample
  if (!i2s.begin(sampleRate)) {
    Serial.println("Failed to initialize I2S!");
    while (1); // do nothing
  }

    Serial.println("core0 - setup done");

}


void setup1() {
  rp2040.fifo.pop();
  Serial.println("core1 - starting setup");
  core1State.setup(&mcp);
  Serial.println("core1 - setup done");

  rp2040.fifo.push(123);

}


void loop() {
  core0State.loop();
}



void loop1() {  
  core1State.loop();

}

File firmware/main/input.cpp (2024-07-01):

#include "input.h"

InputState::InputState() {

    for (int i = 0; i < NUM_SOUND_BUTTONS; i++) {
        isActive[i] = false;
        lastChange[i] = 0;
    }

    lastChordStart = 0;
    chordStarted = false;
    currentChord = 0;
    lastMuted = 0;
    muteState = false;
    disable = false;
    
}

void InputState::setMcp(Adafruit_MCP23X17 *mcpIf) {
    mcp = mcpIf;
    setUpInputIO();
}

void InputState::setUpInputIO() {

    // pinMode(SOUND_S0, OUTPUT);
    // pinMode(SOUND_S1, OUTPUT);
    // pinMode(SOUND_S2, OUTPUT);
    // pinMode(SOUND_A, INPUT);

    Serial.println("Starting MCP23017 init");

    IO_I2C_IF.setSDA(IO_I2C_SDA);
    IO_I2C_IF.setSCL(IO_I2C_SCL);

    IO_I2C_IF.begin();

    if (!mcp->begin_I2C(MCP23XXX_ADDR, &IO_I2C_IF)) {
      Serial.println("Error Init MCP23017");
      while(1);
    }

    mcp->pinMode(8, INPUT_PULLUP);
    mcp->pinMode(9, INPUT_PULLUP);
    mcp->pinMode(10, INPUT_PULLUP);
    mcp->pinMode(11, INPUT_PULLUP);

    mcp->pinMode(12, INPUT_PULLUP);
    mcp->pinMode(13, INPUT_PULLUP);
    mcp->pinMode(14, INPUT_PULLUP);

}

void InputState::disableInput() {

    disable = true;
}

uint32_t InputState::pollSoundButtonsWithInactiveCooldown() {

    if (disable) {
        return 0;
    }

    uint32_t v = 0;
    bool pinIsActive;
    uint64_t currentTime = millis();

    for (int i = 0; i < NUM_SOUND_BUTTONS; i++) {
        pinIsActive = pollSoundButton(i);
      
        if ((currentTime - lastChange[i]) > DEBOUNCE_MS) {

            if (isActive[i] != pinIsActive) {
                lastChange[i] = currentTime;
                isActive[i] = pinIsActive;

                // start chord if not already started
                if (pinIsActive && !chordStarted) {
                    chordStarted = true;
                    lastChordStart = currentTime;
                    currentChord = 0;
                }

            }

            if (pinIsActive) {
                v |= (1 << i);
                isActive[i] = true;
            } else {
                isActive[i] = false;
            }

        }
    }

    return v;
}

bool InputState::pollSoundButton(int button) {


    int pinId = IO_B0;
    
    switch (button) {

    case 0:
        pinId = IO_B0;
        break;
    case 1:
        pinId = IO_B1;
        break;
    case 2:
        pinId = IO_B2;
        break;
    case 3:
        pinId = IO_B3;
        break;
     
    }

    return mcp->digitalRead(pinId) == SOUND_ACTIVE;
    //return false;
}


bool InputState::pollMuteButton() {
   
    return mcp->digitalRead(IO_ROT_DOWN) == 0;
    //return false;
}

bool InputState::isMuted() {

    if (disable) {

        return false;
    }

    uint64_t currentTime = millis();

    bool muteCapture = pollMuteButton();

    if ((currentTime-lastMuted) > DEBOUNCE_MS) {
        lastMuted = currentTime;
        muteState = muteCapture;
        return muteCapture;
    }

    return muteState;
}

// TODO tidy up this
std::optional<uint32_t> InputState::getNextSound() {

    if (disable) {
        return {};
    }
      

    uint64_t currentTime = millis();

    uint32_t buttonCapture = pollSoundButtonsWithInactiveCooldown();

    if (chordStarted) {

        currentChord |= buttonCapture;

        // check if the chord wait time has elapsed, if so then we can commit to a sound and buffer
        if ((currentTime - lastChordStart) > CHORD_WAIT_TIME_MS) {

            chordStarted = false;
            lastChordStart = currentTime;

            return currentChord;
        }
    }

    return {};

}

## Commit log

2023-12-30 wip interrupts
2024-01-03 one bug fixed, another one pops up :(
    [wav.cpp]
2024-01-12 playback not working :/
    [core0.cpp, core1.cpp, wav.cpp]
2024-01-13 replace rp2040 fifo with library
    [buf.cpp, core0.cpp, core1.cpp]
2024-01-19 single sound button works. still need to make eviction policy + way for second core to see what buffers are done playing
2024-01-20 wip - bug with playback
    [buf.cpp, core0.cpp, core1.cpp]
2024-01-20 fix eviction and race condition
    [core0.cpp, core1.cpp]
2024-02-29 wip pcb
    [Pico.skp, Test.kicad_pcb, Test.kicad_sch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]
2024-03-07 update pcb
    [board.kicad_sch, input.kicad_sch, power.kicad_sch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]
2024-03-09 update wip
    [board.kicad_pcb, board.kicad_sch, input.kicad_sch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]
2024-04-07 wip case
    [bottomCase.scad, dimensions.scad, ioBoard.scad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]
2024-04-08 working with current hardware. still a race condition somewhere with muting i think
    [.#ioBoard.scad, bottomCase.scad, dimensions.scad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]
2024-04-08 need to fix emacs
    [.#ioBoard.scad]
2024-04-08 last minute error handling for eclipse outing
    [topLid.scad]
2024-04-16 update with rp2040, instead of rpi pico. wip
    [board.kicad_sch, power2.kicad_sch, rp2040.kicad_sch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]
2024-04-26 update, schematic should be done
    [board.kicad_pcb, board.kicad_sch, input.kicad_sch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]
2024-05-05 separate io board from main
    [board.kicad_pcb, board.kicad_sch, io-board.kicad_pcb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]
2024-05-05 remove io-board stuff from the main board project
    [board.kicad_pcb, board.kicad_sch, power2.kicad_sch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]
2024-05-19 updated with new pcb
    [mainBoard.scad, power.kicad_sch]
2024-05-19 rename "pico" directory to "firmware"
2024-05-26 Update readmes. Uncovered I2C bug :(
    [board.kicad_pcb, board.kicad_sch, power.kicad_sch]
2024-05-26 * pcb/README.md: update readmes... again
2024-05-26 Update readme and pcb
    [board.kicad_pcb, board.kicad_sch, power.kicad_sch]
2024-05-28 update case pcbs and start on final case design
    [dimensions.scad, ioBoard.scad, mainBoard.scad]
2024-05-29 manually trigger sound and update the pcb layout
    [board.kicad_pcb]
2024-06-10 pcb version 0.3
    [board.kicad_pcb, board.kicad_sch, io-board.kicad_pcb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]
2024-06-10 pcb v0.3
    [board-B_Cu.gbl, board-B_Mask.gbs, board-B_Paste.gbp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]
2024-06-10 Doc update for pcb v0.3
2024-06-28 small update
    [bottomCase.scad, pcbFrame.scad]
2024-06-30 update firmware with some v0.3 pcb stuff
    [power.kicad_sch]
2024-07-01 it works! need to update readmes with pcb v0.3 results
2024-07-04 update readmes with pcb v0.3
2024-07-05 WIP: case
    [dimensions.scad, ioBoard.scad, pcbFrame.scad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]
2024-07-11 update with slacks for printing
    [pcbFrame.scad, speaker.scad]
2024-07-15 update case, and remove hardcoded delay in firmware
    [bodyShape.scad, ioBoard.scad, mainBoard.scad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]
2024-07-28 update io pcb
    [io-board.kicad_pcb, io-board.kicad_sch, t2.stl]
